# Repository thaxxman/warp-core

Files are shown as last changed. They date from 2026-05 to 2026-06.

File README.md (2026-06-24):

# 🔥 Warp Core eHMD

> **⚠️ WORK IN PROGRESS — Not Production Ready**
>
> This project is actively being developed and iterated. Hardware pin assignments, firmware behavior, BLE protocol fields, and the Android app UI are all **subject to change** without notice. Some components listed below may be obsolete or mislabeled. Build at your own risk, and expect to reflash the firmware as updates land. The final design is not yet stable.
>
> **Current challenges:**
> 1. **Power draw vs. PD limits** — When cold, the MCH element's inrush pulls hard enough to trip the overcurrent protection on the USB-C PD charger (100W / 20V 5A ceiling). Balancing startup current without sacrificing heat-up speed is still being worked out.
> 2. **MCH element selection** — Finding a ceramic MCH heating element that hits the right trade-off between wattage output and heat dispersion for this form factor. The current element works but isn't optimal.

An open-source Electronic Heat Management Device for hookah. The Warp Core replaces traditional charcoal with a PID-controlled MCH heating element, delivering precise, consistent temperature management through a sleek Android app and an on-device OLED display.





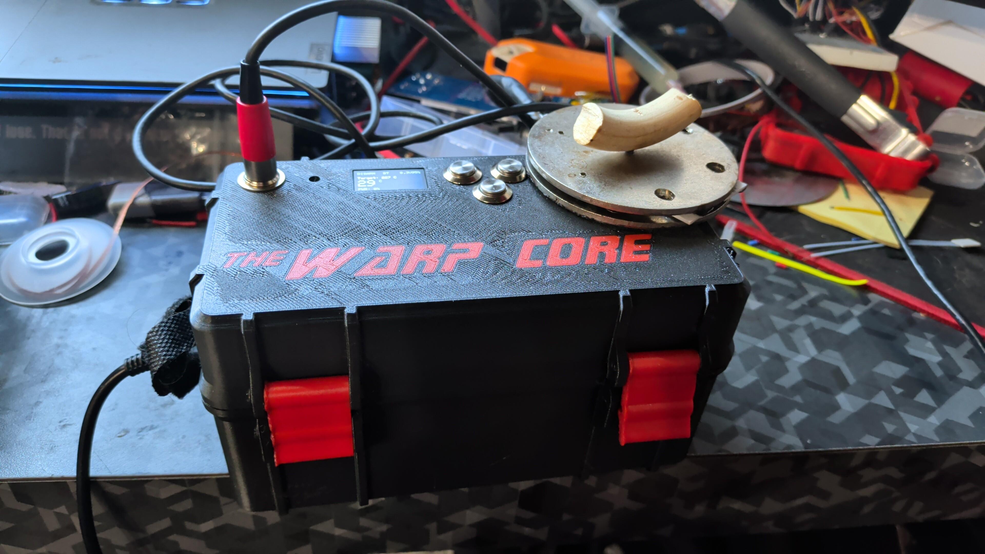
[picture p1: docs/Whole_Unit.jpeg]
Warp Core eHMD Assembled

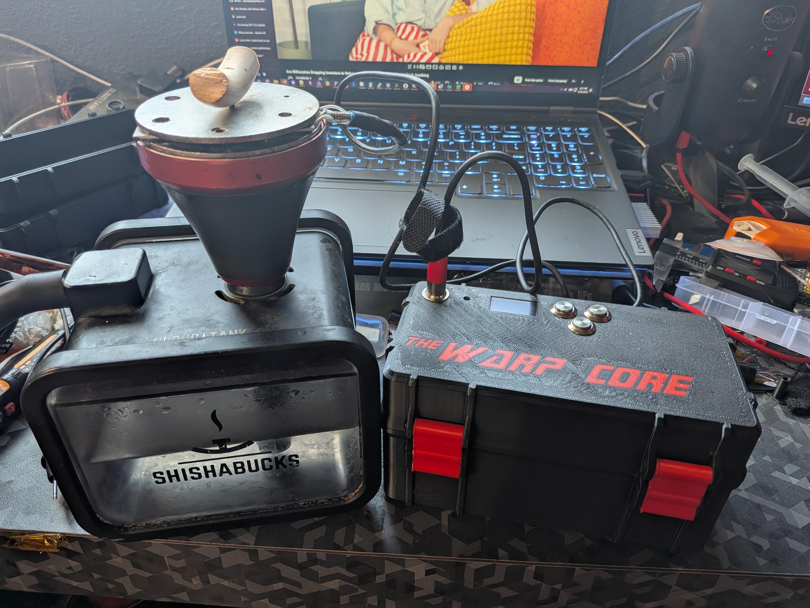
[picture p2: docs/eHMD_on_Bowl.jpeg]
Warp Core eHMD on Hookah

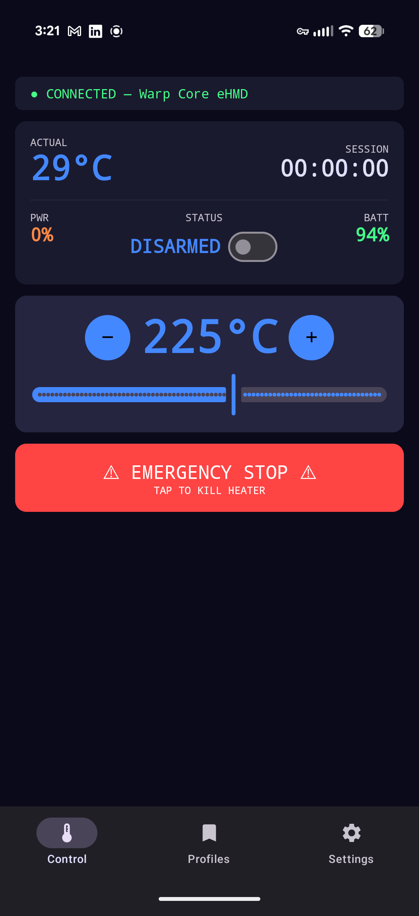
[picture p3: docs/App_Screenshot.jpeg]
Warp Core App Screenshot

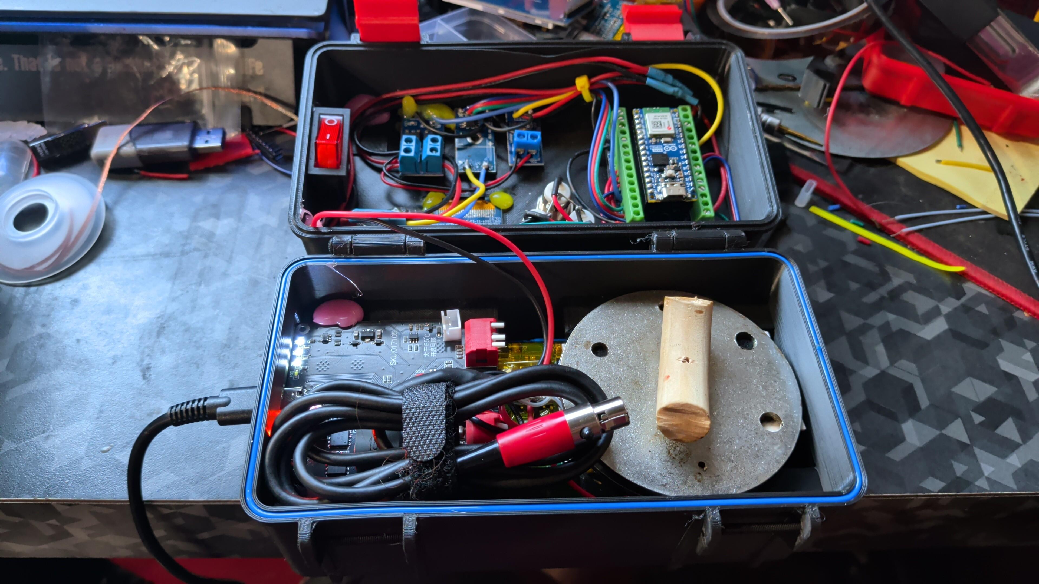
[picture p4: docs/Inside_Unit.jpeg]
Warp Core Inside


## What Is It?

The Warp Core eHMD is a DIY electronic heat management device that sits on top of a hookah bowl, replacing charcoal entirely. A K-type thermocouple reads the real-time temperature, a PID controller drives a ceramic MCH heating element via silent 20 kHz PWM, and an OLED screen on the base station shows you exactly what's happening — no guesswork.

The companion Android app connects over Bluetooth Low Energy and gives you a temperature slider, ±step buttons (configurable 1–10° per tap), preset profiles, live session graphs, and an emergency stop button. Set it, arm it, and let the Warp Core hold your temperature within a few degrees for the entire session.

**Key features:**

- **PID temperature control** — holds your set point within ±2°C at steady state
- **Silent operation** — 20 kHz MOSFET PWM, no audible coil whine
- **0–400°C range** — adjust from the app or on-device buttons
- **BLE Android app** — temperature control, profiles, session logging, CSV export
- **On-device OLED** — live temp, PWM output, safety ramp status, and session timer
- **Safety first** — thermal runaway detection, emergency stop, auto-disarm on fault
- **Configurable step size** — ±1° to ±10° per button tap, set in the app's Settings
- **Open source** — hardware + firmware + app, MIT license, build your own

---

## How It Works

The device has two physical assemblies:

**The eHMD Head** — a layered sandwich that sits on the hookah bowl:
1. Bottom steel plate — the foundation, drilled for the M3 clamp screw
2. Graphite thermal sheet — distributes heat evenly across the MCH element
3. MCH ceramic heating element — the business end, driven by the MOSFET
4. Carbon wool — insulates heat upward into the bowl, not downward
5. Top steel plate — clamps everything down, countersunk for the M3 screw

A K-type thermocouple tip sits in a cutout in the graphite layer, reading the actual interface temperature. The whole stack is clamped together with a steel M3 screw through the center, with a wooden handle on the protruding end.

**The Base Station** — the electronics box that houses:
- Arduino Nano ESP32 (brains + BLE radio)
- SSD1306 128×64 OLED display (I2C on D2/SDA, D3/SCL)
- 3 navigation buttons (left, right, press/select)
- MOSFET trigger board driving the MCH element (PWM on D4)
- MAX6675 thermocouple amplifier
- Piezo buzzer for alerts
- Powered by any **20V 5A USB-C PD** source — no internal battery, no battery monitoring

The head and base station connect via a 4-conductor cable with Mini XLR connectors — two wires for MCH power (18 AWG minimum) and two for the thermocouple signal.

---

## Bill of Materials

### Per-Unit Hardware (what goes into one device)

| Component | Unit Cost | Source |
|---|---|---|
| Steel Plate (2×) | $9 | [Amazon](https://www.amazon.com/dp/B0FWJNRSWB) |
| MCH Heating Element | $16 | [AliExpress](https://www.aliexpress.us/item/3256808961658582.html) |
| Arduino Nano ESP32 | $21 | [Amazon](https://www.amazon.com/dp/B0C947BHK5) |
| OLED Screen (1 of 5-pack) | $2.60 | [Amazon](https://www.amazon.com/dp/B0F5WPZJ92) |
| Voltage Detection Board (1 of 5) | $1.20 | [Amazon](https://www.amazon.com/dp/B01HTC4XKY) |
| MOSFET Trigger Board (1 of 6) | $0.83 | [Amazon](https://www.amazon.com/dp/B0FMJH3DML) |
| Push Buttons (3 of 5) | $3.60 | [Amazon](https://www.amazon.com/dp/B0FM8QKSM1) |
| Arduino Expansion Board (1 of 3) | $4.00 | [Amazon](https://www.amazon.com/dp/B0C9TMRL13) |
| Graphite Thermal Sheet | $0.29 | [Amazon](https://www.amazon.com/dp/B0C69BDLPX) |
| Carbon Wool | $0.10 | [Amazon](https://www.amazon.com/dp/B0CFL5PZWC) |
| K-Type Thermocouple (1 of 5) | $2.40 | [Amazon](https://www.amazon.com/dp/B0D17S7N5B) |
| **Per-unit subtotal** | **~$51** | |

**Per-unit total: ~$51 (battery-less)** — the design no longer uses an internal battery pack. Power via 20V USB-C PD.

### Consumables (buy once, use across many builds)

| Item | Cost | Per-Unit Burn |
|---|---|---|
| Kapton Tape | $10 | ~$0.25 |
| Screw Kit | $6 | ~$0.15 |
| Silicone Wire Kit | $12 | ~$0.50 |
| PLA Filament (1 kg, uses ~250g) | $19 | $4.75 |

**Max out-of-pocket: ~$66**

---

## Wiring Diagram

| Pin | Function | Direction |
|-----|---|---|
| D4 | MOSFET Signal | Output (digitalWrite bang-bang, ~50 Hz cycle) |
| D5 | Press/Select Button | Input (PULLUP) |
| D6 | Right Button | Input (PULLUP) |
| D7 | Left Button | Input (PULLUP) |
| D8 | Buzzer | Output (PWM ch0) |
| D10 | MAX6675 SCK | Output |
| D11 | MAX6675 CS | Output |
| D12 | MAX6675 SO | Input |
| D2 | OLED SDA (I2C) | I/O |
| D3 | OLED SCL (I2C) | Output |
| VIN | System power (20V USB-C PD) | Power in |
| 3V3 | Sensor power (3.3V) | Power out |

All buttons wire between their pin and GND — internal pull-ups are enabled, no external resistors needed.

See [Wiring Diagram](docs/Wiring%20Diagram.md) for full connection details.

---

## Assembly Instructions

Complete step-by-step build guide including LiPo safety briefing, battery pack assembly, Arduino IDE setup, thermocouple welding, and eHMD head construction:

**[Assembly Instructions →](docs/ASSEMBLY_INSTRUCTIONS.md)**

---

## Quick Start

### Flash the Arduino

1. Install [Arduino IDE 2.x](https://www.arduino.cc/en/software)
2. Add ESP32 board support — `File → Preferences → Additional Board Manager URLs`:
   ```
   https://espressif.github.io/arduino-esp32/package_esp32_index.json
   ```
3. Install the board package: `Tools → Board → Boards Manager → search "esp32" → Install`
4. Select **Arduino Nano ESP32** and the correct serial port
5. Install these libraries via `Sketch → Include Library → Manage Libraries`:

| Library | Author |
|---|---|
| Adafruit GFX Library | Adafruit |
| Adafruit SSD1306 | Adafruit |
| MAX6675 | Adafruit |
| PID_v1 | Brett Beauregard |
| ArduinoJson | Benoit Blanchon (v7) |

6. Open `arduino/WarpCore_eHMD.ino` and click **Upload**
7. Open Serial Monitor at 115200 baud to verify boot

### Install the Android App

1. Download `WarpCore-v1.0-debug.apk` from [Releases](../../releases)
2. Enable "Install from unknown sources" on your Android device
3. Install the APK
4. Grant Bluetooth and Location permissions on first launch
5. Power on the Warp Core, tap **Connect**

### Build from Source

```bash
cd android-app
./gradlew assembleDebug
# APK output: app/build/outputs/apk/debug/WarpCore-v1.0-debug.apk
```

---

## BLE Protocol

The ESP32 advertises as **"WarpCore-eHMD"** and exposes a single service:

- **Write characteristic** — app sends JSON: `{"cmd":"set_temp","val":200}`, `{"cmd":"arm","val":1}`, `{"cmd":"e_stop"}`, etc.
- **Notify characteristic** — ESP32 pushes status every 500ms: `{"status":"ok","temp_set":200,"temp_actual":198,"armed":1,"pwm":45,"session":120}`

Full protocol docs: [docs/BLE_PROTOCOL.md](docs/BLE_PROTOCOL.md)

---

## 3D Printed Enclosure

STL files in `docs/`:
- Box Bottom
- Box Lid
- Box Latch

---

## Project Structure

```
WarpCore-eHMD/
├── android-app/          # Kotlin + Jetpack Compose Android app
│   └── app/src/main/java/com/redshirt/warpcore/
│       ├── ble/          # BLE scan, connect, JSON protocol
│       ├── data/         # Room database (profiles, session logs)
│       ├── ui/           # Compose UI (screens, components, theme, navigation)
│       └── viewmodel/    # ConnectionViewModel, SettingsViewModel
├── arduino/             # ESP32 firmware
│   ├── WarpCore_eHMD.ino
│   └── pitches.h
├── docs/
│   ├── ASSEMBLY_INSTRUCTIONS.md
│   ├── BLE_PROTOCOL.md
│   ├── TODO.md
│   ├── Wiring Diagram.md
│   ├── Warp Core - Box Bottom.stl
│   ├── Warp Core - Box Lid.stl
│   └── Warp Core - Box Latch.stl
├── LICENSE
└── README.md
```

---

## Safety

This device controls a heating element that can reach **400°C (752°F)**.

- **Safety ramp**: When arming, PWM is capped at 40% until the thermocouple reads 50°C, then linearly ramps to full power at 200°C. This prevents runaway if the heater is powered before it's properly seated on the bowl
- **Thermal runaway protection**: If actual temp exceeds set temp by 50°C for 5 consecutive readings (~1.25s), the heater is killed, armed state cleared, and an alarm sounds
- **Never** leave the device unattended while armed
- The emergency stop button (long-press on device or in-app button) immediately kills heater power

You are responsible for safe assembly and operation. This project is provided as-is with no warranty.

---

## License

[MIT License](LICENSE) — use it, mod it, sell it. Just include the original license.

---

*Built by [George Thaxton](https://github.com/Thaxxman). Open source, open invitation.*

[☕ Buy me a Bowl](https://paypal.me/GThaxton)

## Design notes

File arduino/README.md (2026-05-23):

# Warp Core eHMD — Arduino Firmware

## Overview
Electronic Heat Management Device firmware for Arduino Nano ESP32.
Controls a heating element via PID, reads temperature from MAX6675 thermocouple,
displays on SSD1306 OLED, and communicates with the Android app over BLE.

## Hardware Pin Mapping (Arduino Nano ESP32)

| Pin | Function |
|-----|---|
| D9  | MOSFET PWM (heater control) |
| D10 | MAX6675 SCK |
| D11 | MAX6675 CS |
| D12 | MAX6675 SO (MISO) |
| D5  | Joystick Press (arm/disarm & set mode) |
| D6  | Joystick Right (temp up) |
| D7  | Joystick Left (temp down) |
| D8  | Buzzer (PWM audio) |
| A7  | Battery voltage divider |

## Required Libraries
Install via Arduino Library Manager (Sketch → Include Library → Manage Libraries):

1. **Adafruit GFX Library** — Display graphics
2. **Adafruit SSD1306** — OLED driver
3. **MAX6675** — Thermocouple library (or use the raw library included)
4. **PID_v1** — PID controller
5. **ArduinoJson** — v7, JSON parsing for BLE commands

ESP32 BLE libraries are built into the ESP32 Arduino Core — no separate install needed.

## Board Setup
- Board: "Arduino Nano ESP32" (or "ESP32 Dev Module" if using generic ESP32)
- The code uses `analogSetAttenuation`, `analogReadResolution`, and ESP32-specific `ledc` functions

## Building & Flashing
1. Open `WarpCore_eHMD.ino` in Arduino IDE
2. Select Board: Arduino Nano ESP32
3. Select Port: (your device's COM port)
4. Click Upload

## BLE Protocol
See `../docs/BLE_PROTOCOL.md` for the full specification.

## Local Controls (Buttons)
- **Long press (>3s)**: Arm / Disarm (3s hold)
- **Short press**: Enter / Exit set mode
- **Left/Right in set mode**: Adjust temperature (±1, hold for ±5)
- All local changes are reflected in the next BLE status update

## Safety Features
- Max temperature: 400°C (enforced in firmware and app)
- Thermal runaway: If actual temp exceeds set temp by 50°C for 5 consecutive readings (~1.25s), heater is killed, armed state cleared, alarm sounds
- Sensor fault: If thermocouple reads NaN, heater is killed and alarm sounds
- Emergency stop: App sends `{"cmd":"e_stop"}`, immediately kills heater

## EEPROM Layout
Stores: setTemp (double), Kp (double), Ki (double), Kd (double)
Values persist across power cycles. Defaults to 100°C, Kp=2, Ki=5, Kd=1.

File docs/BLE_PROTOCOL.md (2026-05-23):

# Warp Core eHMD — BLE Protocol Specification

## GATT Service Definition

| Item | UUID |
|---|---|
| Service | `4fafc201-1fb5-459e-8fcc-c5c9c331914b` |
| Write Characteristic (App → ESP32) | `beb5483e-36e1-4688-b7f5-ea07361b26a8` |
| Notify Characteristic (ESP32 → App) | `beb5483e-36e1-4688-b7f5-ea07361b26a9` |

## MTU

Request 512-byte MTU on connection. All messages fit well within this.

## Connection Parameters

- Request connection interval: 30-50ms (for responsive slider control)
- ESP32 advertises as: `Warp Core eHMD`

## Data Format

All messages are JSON. One command per BLE write. One status update per notify.

---

## App → ESP32 Commands (Write Characteristic)

### Set Target Temperature
```json
{"cmd":"set_temp","val":200}
```
- `val`: integer, 0–400 (Celsius)
- ESP32 enforces 0–400 range independently

### Arm / Disarm
```json
{"cmd":"arm","val":1}
```
```json
{"cmd":"arm","val":0}
```
- `val`: 1 = arm, 0 = disarm

### Emergency Stop
```json
{"cmd":"e_stop"}
```
- ESP32 immediately kills heater PWM, sets armed = false, sounds alarm tone
- App should send this repeatedly until acknowledged

### Request Full Status
```json
{"cmd":"get_status"}
```
- ESP32 responds with full state notify

### Set PID Parameters
```json
{"cmd":"set_pid","kp":2.0,"ki":5.0,"kd":1.0}
```
- Values stored in EEPROM alongside setTemp
- Only available via app (advanced settings)

---

## ESP32 → App Notifications (Notify Characteristic)

### Periodic Status Update (every 500ms when connected)
```json
{"status":"ok","temp_set":200,"temp_actual":198,"armed":1,"pwm":73,"battery":85,"session":1847}
```

| Field | Type | Unit | Notes |
|---|---|---|---|
| `status` | string | — | "ok", "error", "red_alert" |
| `temp_set` | int | °C | Current target temperature |
| `temp_actual` | float | °C | From thermocouple, -1 if sensor error |
| `armed` | int | — | 1 = armed, 0 = disarmed |
| `pwm` | int | % | PWM output as percentage (0–100) |
| `battery` | int | % | Battery level |
| `session` | int | seconds | Elapsed seconds since arm, 0 if disarmed |

### Red Alert (Thermal Runaway)
```json
{"status":"red_alert","temp_set":200,"temp_actual":267,"armed":0,"pwm":0,"battery":85,"session":1847}
```
- Heater is killed (`armed` = 0, `pwm` = 0)
- Buzzer sounds on device
- App should show prominent Red Alert UI

### Sensor Error
```json
{"status":"error","msg":"sensor_fault","temp_actual":-1}
```

### Disconnection Notification
On BLE disconnect, ESP32:
- Continues current operation (stays armed if armed)
- Sounds disconnect tone (ascending then descending tone)
- Shows BT disconnect icon on OLED
- Does NOT shut down heater

---

## Session Timer Logic

- Timer starts when `armed` transitions 0 → 1
- Timer resets to 0 when `armed` transitions 1 → 0
- Timer value included in every status update as `session` (integer seconds)
- Timer continues even if BLE disconnects and reconnects

---

## Thermal Runaway Detection

- Triggered when `temp_actual` exceeds `temp_set` by 50°C for 5 consecutive readings (readings at 250ms intervals = ~1.25 seconds sustained)
- Actions: kill heater, set armed = 0, sound alarm tone on buzzer, send red_alert status, show "RED ALERT" on OLED
- Latched: requires manual disarm/rearm or app e_stop + rearm to clear

---

## F/C Conversion

All BLE communication uses Celsius. The app is responsible for:
- Displaying in user's preferred unit (set in app settings)
- Converting slider/input values from F→C before sending `set_temp`
- Converting received `temp_actual` and `temp_set` from C→F for display (when F mode active)

Conversion: F = C × 9/5 + 32, C = (F − 32) × 5/9

---

## Profiles

Profiles are stored only on the app side (not on ESP32). A profile contains:
- Name (string)
- Target Temp (integer, stored in preferred unit, sent as °C)

The app sends a normal `set_temp` command when applying a profile. No special protocol needed.

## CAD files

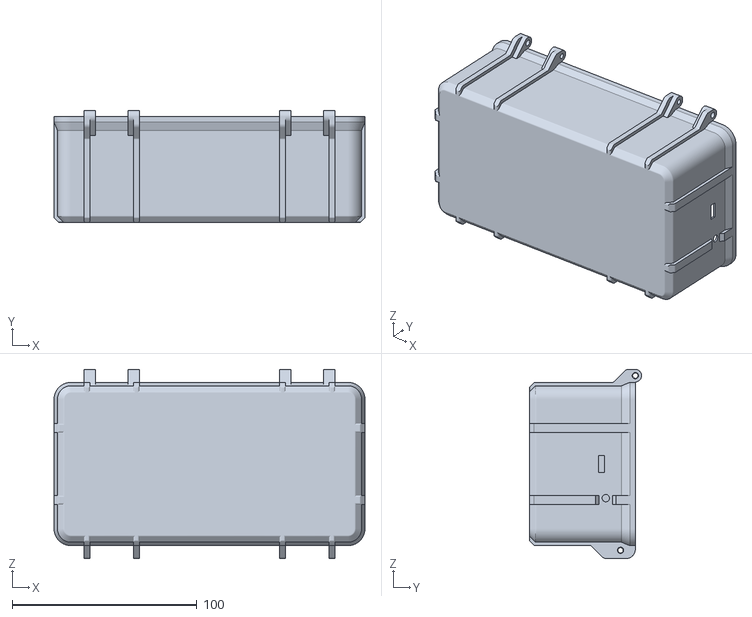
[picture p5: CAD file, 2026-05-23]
docs/Warp Core - Box Bottom.stl
168.5 x 60.8 x 102.5

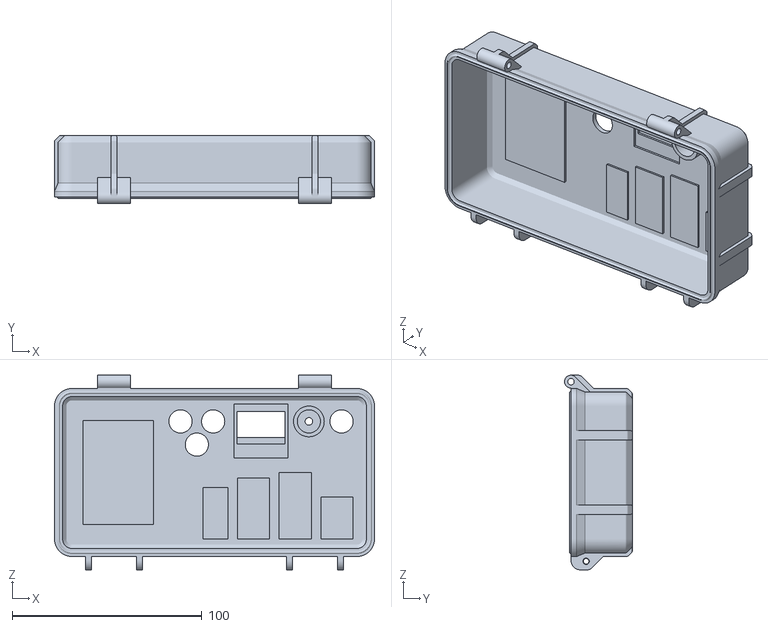
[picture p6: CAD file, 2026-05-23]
docs/Warp Core - Box Lid.stl
168.5 x 35.8 x 102.5

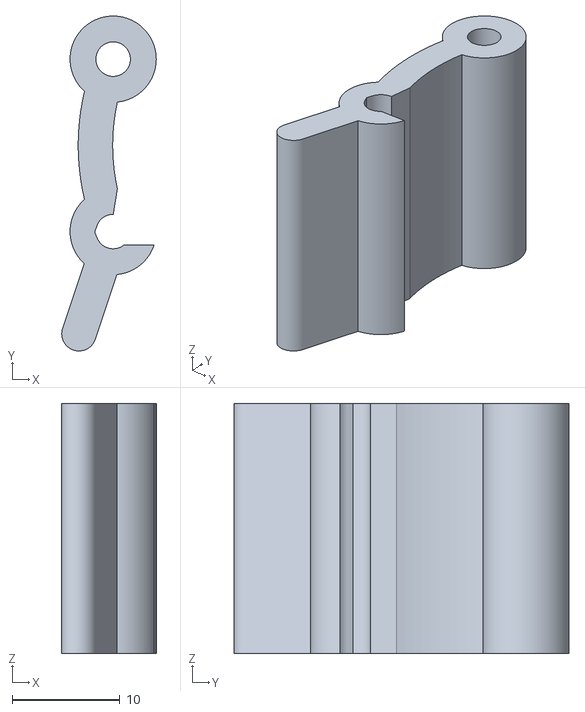
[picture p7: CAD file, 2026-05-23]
docs/Warp Core - Box Latch.stl
8.77 x 31.1 x 23.2

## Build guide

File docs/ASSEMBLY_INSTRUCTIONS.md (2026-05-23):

# Warp Core eHMD — Arduino Nano ESP32 Assembly Instructions

## 1. 3D Print the Enclosure

Print the included STL files. Recommended settings:

- **Material:** PLA (or PETG for higher heat resistance near the heater)
- **Infill:** 20–30%
- **Walls:** 3 perimeters minimum
- **Supports:** Per STL — review each for overhangs before printing

Assemble printed parts with M3 screws.

---

## 2. Wire the Arduino Components

Place and wire all components following the wiring guide below. Secure each component with hot glue. Keep wire runs as short as practical. Use zip ties where needed to manage routing.

| Component | Wire | ESP32 Pin | Notes |
|---|---|---|---|
| **MAX6675 Thermocouple** | | | |
| | SCK | D10 | SPI clock |
| | CS | D11 | Chip select |
| | SO | D12 | SPI data out |
| | VCC | 3V3 | |
| | GND | GND | |
| **MOSFET Trigger Board** | | | |
| | Signal | D9 | PWM ch1, 20 kHz (ultrasonic) |
| | VCC | VIN (5V from battery) | |
| | GND | GND | |
| **Buzzer** | | | |
| | + | D8 | PWM ch0 |
| | − | GND | |
| **Left Button** | | | |
| | Common | GND | |
| | NO | D7 | INPUT_PULLUP — no resistor needed |
| **Right Button** | | | |
| | Common | GND | |
| | NO | D6 | INPUT_PULLUP — no resistor needed |
| **Press/Select Button** | | | |
| | Common | GND | |
| | NO | D5 | INPUT_PULLUP — no resistor needed |
| **OLED Display (SSD1306)** | | | I2C address 0x3C |
| | SDA | A4 | I2C data |
| | SCL | A5 | I2C clock |
| | VCC | 3V3 | |
| | GND | GND | |
| **Voltage Detection Board** | | | |
| | Signal out | A7 | Analog read |
| | VCC | Battery + | Monitors pack voltage |
| | GND | GND | |

**Unused GPIOs:** D2, D3, D4 are available for future expansion.

**Power routing:**
- **VIN** receives 5V from the charging module output (powers the ESP32 and MOSFET board)
- **3V3** powers the thermocouple IC, OLED, and logic-level references
- **GND** is common to all components — star ground preferred

---

## 3. Assemble the 2S2P Battery Pack

### ⚠️ LIPO SAFETY BRIEFING — READ THIS ENTIRE SECTION BEFORE STARTING

Lithium Polymer (LiPo) batteries store enormous energy in a small package. Mishandling them can cause **fire, explosion, chemical burns, and property damage.** Treat them with the same caution you'd give to a loaded firearm.

**The risks are real:**

- A punctured, overcharged, or shorted LiPo cell can undergo **thermal runaway** — the cell vents hot gas, catches fire, and cannot be extinguished with water or a standard fire extinguisher. It burns until the fuel is spent.
- A **2S pack** sits at 8.4V when fully charged. Shorting the terminals will dump 30+ amps instantly — enough to melt wire, weld metal, and start a fire.
- **Never** charge a swollen, dented, or damaged cell. Dispose of it instead.
- **Never** charge unattended. Stay in the same room.
- **Never** puncture, crush, or disassemble a cell.
- **Never** short the terminals together, even momentarily.
- **Always** charge on a non-flammable surface (concrete, ceramic tile, steel). Not on a desk, not on carpet, not on wood.
- **Keep a LiPo fire bag or sand bucket nearby** when charging. A class D fire extinguisher is ideal; a standard ABC extinguisher will not stop a LiPo fire.
- If a cell **swells, gets hot to the touch, or smells sweet/burnt**, move it outdoors away from combustibles immediately and do not use it again.

**You are responsible for your own safety.** If you are not comfortable working with LiPo cells, ask someone with experience to help.

### Assembly Instructions

You need: **4× 146074 LiPo cells** (2 pairs in parallel, those 2 pairs in series), **1× 2S BMS board**, **silicone wire** (18AWG for power, 22–26AWG for balance), **heat shrink tubing** (for each cell and for the pack), **soldering iron**, **multimeter**, **Kapton tape**.

**Step 1 — Inspect and charge cells individually**

- Check each cell for swelling, dents, or damage. Discard any suspect cell.
- Charge each cell individually to **3.8V (storage charge)** using a balance charger. All four cells must be within **0.05V** of each other before proceeding. Mismatched cells will cause the BMS to cut off prematurely or, worse, overcharge one pair.

**Step 2 — Heat shrink each cell**

- Cut a length of battery heat shrink tubing for each cell. Slide it over the cell and shrink with a heat gun on **low setting** — keep the gun moving. Do not over-shrink; you need the tubing to lie flat. This insulates each cell from its neighbors.

**Step 3 — Create the parallel pairs**

- Place two cells **side by side, same orientation** (both + facing the same direction).
- Tape the pair together with Kapton tape. Wrap tightly but do not crush.
- Solder a short bus wire across the **positive terminals** of both cells. Keep the solder joint small and flat.
- Solder a short bus wire across the **negative terminals** of both cells.
- You now have a "1S2P" cell group rated at ~3.7V nominal, double the capacity. Repeat for the second pair.

**Step 4 — Wire the BMS**

Before soldering, study your BMS pinout. Most 2S BMS boards have these pads:

| Pad | Connects To |
|-----|---|
| B− | Negative of the **lower** cell pair (Pack −) |
| B1 | Junction between the two cell pairs (balance tap) |
| B+ | Positive of the **upper** cell pair (Pack +) |
| P− | Pack output negative (to charging module) |
| P+ | Pack output positive (to charging module) |

- Solder **B−** to the negative of the lower pair.
- Solder **B1** to the junction between the pairs (the common midpoint).
- Solder **B+** to the positive of the upper pair.
- Use **short, thick (18AWG silicone) wires** for P− and P+. These carry full load current.
- Wrap the BMS in Kapton tape to prevent shorts against the cell cans.

**Step 5 — Shrink the full pack**

- Wrap the entire assembly (both pairs + BMS) in battery heat shrink. This holds it together and adds puncture resistance.
- Leave the P+ and P− leads extending out the top, along with the balance leads if your BMS has a separate balance connector.

**Step 6 — Verify with a multimeter**

- Measure the pack voltage at P+ / P−. It should read between **7.4V** (nominal) and **8.4V** (fully charged).
- Measure the midpoint (B1 relative to B−). It should read **~3.7V**.
- If either reading is off by more than 0.1V, **stop and troubleshoot.** A wiring mistake here will destroy the BMS or the cells on the first charge cycle.

---

## 4. Install the Arduino Software

### Install the Arduino IDE

1. Download the Arduino IDE from [https://www.arduino.cc/en/software](https://www.arduino.cc/en/software) (version 2.x recommended).
2. Install it for your operating system (Windows, macOS, or Linux).

### Add ESP32 Board Support

The Arduino Nano ESP32 is not in the default board package. You need to add Espressif's board definitions:

1. Open Arduino IDE → **File → Preferences**.
2. In **Additional Board Manager URLs**, add:
   ```
   https://espressif.github.io/arduino-esp32/package_esp32_index.json
   ```
   (If you already have other URLs, click the button next to the field and add this one on a new line.)
3. Click **OK**.
4. Go to **Tools → Board → Boards Manager**.
5. Search for **esp32**. Install **esp32 by Espressif Systems** (version 3.x or later).

### Select the Board and Port

1. Connect the Arduino Nano ESP32 to your computer via USB-C.
2. Go to **Tools → Board** → select **Arduino Nano ESP32** (under "ESP32 Arduino" group).
3. Go to **Tools → Port** → select the COM port (Windows) or `/dev/cu.usbmodem*` (macOS) that appeared when you plugged in the board.
4. If the board doesn't appear, double-tap the reset button on the Nano to put it in bootloader mode, then try again.

### Install Required Libraries

Go to **Sketch → Include Library → Manage Libraries** and install each of these:

| Library | Author | Version |
|---|---|---|
| Adafruit GFX Library | Adafruit | Latest |
| Adafruit SSD1306 | Adafruit | Latest |
| MAX6675 | Adafruit | Latest |
| PID_v1 | Brett Beauregard | Latest |
| ArduinoJson | Benoit Blanchon | v7.x |

**Important:** Do **NOT** install the "ArduinoBLE" library — the ESP32 Nano uses its built-in NimBLE stack (BLEDevice.h / BLEServer.h), not ArduinoBLE. ArduinoBLE requires a NINA-W102 coprocessor that the ESP32 Nano does not have.

### Upload the Firmware

1. Open the file `arduino/WarpCore_eHMD.ino` from this project.
2. Make sure the board is set to **Arduino Nano ESP32** and the correct port is selected.
3. Click **Upload** (→ arrow button) or press **Ctrl+U**.
4. The IDE will compile and flash the firmware. The Nano's LED will pulse during upload and then the OLED should initialize on reboot.
5. Open **Tools → Serial Monitor** at **115200 baud** to verify boot messages and BLE advertising.

---

## 5. Install the Warp Core Android App

1. Copy the provided `app-debug.apk` to your Android phone.
2. On the phone, open the APK file. You may need to enable **"Install from unknown sources"** in Settings → Security.
3. Install and open the app.
4. Grant Bluetooth and Location permissions when prompted (required for BLE scanning on Android).

---

## 6. Assemble the eHMD

### 6a. Drill the Bottom Plate

- Drill **8× 6mm holes** equidistant around the perimeter. Each hole should have **at least 6mm** of material between the hole edge and the plate edge. These are airflow / ventilation holes for the heater.
- Drill **1× 3mm hole** in the center of the bottom plate. **Countersink** this hole from the top side so the screw head sits flush or slightly below the surface.
- Lightly deburr all holes with a file or deburring tool.

### 6b. Drill and Tap the Top Plate

- Drill a **2.5mm hole** in the center of the top plate (tap drill size for M3).
- **Tap** the hole with an **M3×0.5 thread tap**. Go slow, use cutting oil if available, back the tap out frequently to clear chips. The steel plate is thin — run the tap through 2–3 times to clean the threads.

### 6c. Prepare the Thermocouple Probe

The K-type thermocouple wire is two dissimilar metals (chromel and alumel) welded together at the tip. If you need to shorten or repair the probe:

1. **Strip** the end of the thermocouple wire to expose about 5mm of each conductor (the positive wire is typically non-magnetic chromel, the negative is magnetic alumel).
2. **Twist** the two bare conductors tightly together at the tip.
3. **Weld** the junction using a capacitor-discharge welder, a spot welder, or the "battery method":
   - Take a **fresh AA or 9V battery**.
   - Touch the twisted thermocouple junction briefly to the battery terminal while simultaneously brushing it against the other terminal. The rapid current pulse will resistance-weld the junction.
   - Alternatively, touch the twisted tip to a **lead** strip while applying power from a bench supply (3–5V, current-limited to ~10A) for a split second. The lead melts and fuses the junction.
4. **Test** the joint with your multimeter set to millivolts. Warm the tip with your fingers — you should see a small voltage change (roughly 0.04mV per °C).
5. Insulate the wires above the junction with a small piece of **Kapton tape** or fiberglass sleeving. The junction itself must remain exposed (metal-to-metal contact with the graphite sheet).

Cut the thermocouple to roughly **5 inches** (127mm) overall length before welding the tip. This gives enough wire to route from the eHMD down to the Arduino, with some slack for strain relief.

### 6d. Layer Assembly

Sandwich the eHMD layers in this order, bottom to top:

| Layer | Component | Notes |
|---|---|---|
| **L1** | Bottom plate | Countersunk center hole facing up |
| **L2** | Graphite sheet | Cut to match the MCH element footprint. Cut a small notch or pocket for the thermocouple tip — the tip must be in direct contact with the graphite. |
| **L3** | MCH heating element | Flat side against the graphite |
| **L4** | Carbon wool | Layer thick enough to fully cover the MCH. This is your thermal insulation and heat distributor. |
| **L5** | Top plate | M3 threaded center hole |

### 6e. Clamp Together

1. Run a **steel M3×20mm screw** up through the bottom plate (from below, countersunk head sits flush), through L2, L3, L4, and thread it into the tapped center hole of the top plate (L5).
2. Tighten firmly — the clamping force should be tight enough to compress the carbon wool slightly and ensure good thermal contact between all layers. Don't overtighten to the point of crushing the MCH element.
3. The 20mm screw leaves ~5–8mm of excess above the top plate. Thread a **wooden handle** onto this protruding stud for easy lifting of the hot eHMD.

### 6f. Wire the MCH and Thermocouple to the Cable

1. Solder the **MCH heating element** leads to a 4-conductor cable:
   - **MCH + (red)** → 18AWG wire (minimum) → XLR pin 1 (or per your XLR pinout)
   - **MCH − (black)** → 18AWG wire (minimum) → XLR pin 2
   - 18AWG is required because the MCH can draw 5–10A at operating voltage.
2. Solder the **K-type thermocouple** leads to the remaining 2 conductors in the cable:
   - **Chromel (+)** → smaller gauge wire → XLR pin 3
   - **Alumel (−)** → smaller gauge wire → XLR pin 4
3. Cover each solder joint with **heat shrink tubing**. Slide the tubing over the joint and shrink with a heat gun.
4. Wrap the entire cable junction with Kapton tape for strain relief and insulation.

### 6g. Install the Mini XLR Connector

At the **base station end** of the cable:

1. Install the **4-pin Mini XLR connector** on the cable end.
2. Pin assignment must match the female socket on the base station:
   - **Pins 1 & 2:** Load output from the MOSFET trigger board (MCH + and −)
   - **Pins 3 & 4:** Thermocouple input to the MAX6675 chip on the Arduino
3. Verify continuity with a multimeter before powering on. A swapped thermocouple polarity will cause the displayed temperature to **decrease** as the heater warms up — an easy mistake to catch.

---

## 7. Charge Before First Use

1. Connect the USB-C charging module to a **65W+ USB-C PD power supply** (laptop charger or similar).
2. A full charge from storage voltage takes approximately **1.5–2 hours**.
3. The BMS will balance the cells and cut off at 8.4V (4.2V per cell).
4. Do not leave charging unattended overnight for the first cycle. Monitor for any swelling, heat, or unusual odor.

---

## 8. Maiden Voyage

1. **Power on** the Arduino Nano ESP32 via USB-C or from the battery through the charging module.
2. The OLED will display the boot screen. The buzzer will play the startup melody.
3. BLE will advertise as **"WarpCore-eHMD"** for **2 minutes**. Open the Android app and tap **Connect**.
4. Once connected, the app transitions to the **Control** screen. You should see the current temperature, set temperature, and controls.
5. **Set your target temperature** using the slider or ± buttons. Default step size is ±1° (adjustable in Settings → Step Size).
6. Press **ARM** to begin heating. The MOSFET will energize and the PID controller will ramp up to target.
7. Monitor the temperature readout. The app updates every 500ms. The OLED also displays live status.
8. When done, press **DISARM** to shut off the heater. The MOSFET drops to 0% PWM.
9. **Emergency Stop** is always available on the Control screen — it immediately kills the heater and sounds a triple-tone alert.

**Congratulate yourself, Captain. The Warp Core is online.** 🖖

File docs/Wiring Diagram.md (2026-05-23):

    Warp Core eHMD — Arduino Nano ESP32 Wiring Diagram

    ┌──────────────────────────────────────────┐
    │          ARDUINO NANO ESP32 (top view)   │
    │                                          │
    │  D13 ─ ─ ─ ─ ─ ─ ─ ─ ─ ─ ─ ─ ─ ─  D12    │
    │  3V3 ─ ─ ─ ─ ─ ─ ─ ─ ─ ─ ─ ─ ─ ─  D11    │
    │  REF ─ ─ ─ ─ ─ ─ ─ ─ ─ ─ ─ ─ ─ ─  D10    │
    │  A0  ─ ─ ─ ─ ─ ─ ─ ─ ─ ─ ─ ─ ─ ─  D9     │
    │  A1  ─ ─ ─ ─ ─ ─ ─ ─ ─ ─ ─ ─ ─ ─  D8     │
    │  A2  ─ ─ ─ ─ ─ ─ ─ ─ ─ ─ ─ ─ ─ ─  D7     │
    │  A3  ─ ─ ─ ─ ─ ─ ─ ─ ─ ─ ─ ─ ─ ─  D6     │
    │  A4  ─ ─ ─ ─ ─ ─ ─ ─ ─ ─ ─ ─ ─ ─  D5     │
    │  A5  ─ ─ ─ ─ ─ ─ ─ ─ ─ ─ ─ ─ ─ ─  D4     │
    │  A6  ─ ─ ─ ─ ─ ─ ─ ─ ─ ─ ─ ─ ─ ─  D3     │
    │  A7  ─ ─ ─ ─ ─ ─ ─ ─ ─ ─ ─ ─ ─ ─  D2     │
    │  5V  ─ ─ ─ ─ ─ ─ ─ ─ ─ ─ ─ ─ ─ ─  GND    │
    │  RST ─ ─ ─ ─ ─ ─ ─ ─ ─ ─ ─ ─ ─ ─  VIN    │
    │  GND ─ ─ ─ ─ ─ ─ ─ ─ ─ ─ ─ ─ ─ ─  3V3_EN │
    └──────────────────────────────────────────┘

    Signal Connections

    | Component               | Wire       | ESP32 Pin      | Notes                    |
    |-------------------------|------------|----------------|--------------------------|
    | MAX6675 Thermocouple    |            |                |                          |
    |                         | SCK        | D10            | SPI clock                |
    |                         | CS         | D11            | Chip select              |
    |                         | SO         | D12            | SPI data out             |
    |                         | VCC        | 3V3            |                          |
    |                         | GND        | GND            |                          |
    |                         | + Probe    | + to eHMD      | This runs to the Mini XLR|
    |                         | - Probe    | - to eHMD      | This runs to the Mini XLR|
    | MOSFET Trigger Board    |            |                |                          |
    |                         | Signal     | D9             | PWM ch1, 20 kHz          |
    |                         | VCC        | 5V or VIN      | From battery via step-up |
    |                         | GND        | GND            |                          |
    | MCH Heater Element      |            |                |                          |
    |                         | Load+      | MOSFET output+ | Through MOSFET board     |
    |                         | Load−      | MOSFET output− | Through MOSFET board     |
    | Buzzer                  |            |                |                          |
    |                         | +          | D8             | PWM ch0                  |
    |                         | −          | GND            |                          |
    | Left Button             |            |                |                          |
    |                         | Common     | GND            |                          |
    |                         | NO         | D7             | INPUT_PULLUP in code     |
    | Right Button            |            |                |                          |
    |                         | Common     | GND            |                          |
    |                         | NO         | D6             | INPUT_PULLUP in code     |
    | Press/Select Button     |            |                |                          |
    |                         | Common     | GND            |                          |
    |                         | NO         | D5             | INPUT_PULLUP in code     |
    | OLED Display (SSD1306)  |            |                | I2C address 0x3C         |
    |                         | SDA        | A4             | I2C data                 |
    |                         | SCL        | A5             | I2C clock                |
    |                         | VCC        | 3V3            |                          |
    |                         | GND        | GND            |                          |
    | Voltage Detection Board |            |                |                          |
    |                         | Signal out | A7             | Analog read              |
    |                         | VCC        | Battery+       | Monitors pack voltage    |
    |                         | GND        | GND            |                          |

    Power Section (battery build only)

    | Component            | Wire  | Connects To                  | Notes                    |
    |----------------------|-------|------------------------------|--------------------------|
    | 2S BMS               |       |                              |                          |
    |                      | B+    | Battery pack +               | 4× 146074 cells in 2S2P  |
    |                      | B−    | Battery pack −               |                          |
    |                      | P+    | 140W Charging Module VIN+    |                          |
    |                      | P−    | 140W Charging Module VIN−    |                          |
    | 140W Charging Module |       |                              |                          |
    |                      | USB-C | —                            | Charge input             |
    |                      | OUT+  | ESP32 VIN + MOSFET VCC       | Powers everything        |
    |                      | OUT−  | Power Switch -               |                          |
    | Power Switch         |       |                              |                          |
    |                      | -     | 140W Out -                   | Charge input             |
    |                      | -     | ESP32 VIN + MOSFET VCC       | Powers everything        |
    | Min XLR Connector    |       |                      		  | eHMD Head                |
    |                      | Pin 1 | + on the LOAD side of MOSFET |                          |
    |                      | Pin 2 | - on the LOAD side of MOSFET |                          |
    |                      | Pin 3 | + Thermal Probe on Max6687   |                          |
    |                      | Pin 2 | - Thermal Probe on Max6687   |                          |
    | Battery Heatshrink   | —     | Wraps each cell              | Insulation between cells |

    Voltage Divider (for battery monitoring — built from resistors or uses the voltage detection board)

    Battery+ ──┬── 30kΩ (rOhm1) ──┬── A7
                │                   │
                │               7.5kΩ (rOhm2)
                │                   │
                └───────────────── GND

    Calibrated with voltageCalibration = 1.1038. If using the voltage detection board from the BOM, it likely has this divider built in — just wire its signal out to A7.

    Summary of all ESP32 pin assignments:

    | Pin | Function            | Direction                |
    |-----|---------------------|--------------------------|
    | D2  | Available           | —                        |
    | D3  | Available           | —                        |
    | D4  | Available           | —                        |
    | D5  | Press/Select Button | Input (PULLUP)           |
    | D6  | Right Button        | Input (PULLUP)           |
    | D7  | Left Button         | Input (PULLUP)           |
    | D8  | Buzzer              | Output (PWM ch0)         |
    | D9  | MOSFET Signal       | Output (PWM ch1, 20 kHz) |
    | D10 | MAX6675 SCK         | Output                   |
    | D11 | MAX6675 CS          | Output                   |
    | D12 | MAX6675 SO          | Input                    |
    | A4  | OLED SDA (I2C)      | I/O                      |
    | A5  | OLED SCL (I2C)      | Output                   |
    | A7  | Voltage Sense       | Input (Analog)           |
    | VIN | System power (5V)   | Power in                 |
    | 3V3 | Sensor power (3.3V) | Power out                |
    | GND | Common ground       | Ground                   |

    Buttons are wired between the pin and GND — the code uses INPUT_PULLUP so no external resistors needed. When pressed, the pin goes LOW.

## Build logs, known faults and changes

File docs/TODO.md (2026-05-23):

# Warp Core eHMD — TODO List

## BLE Pairing (Goal — Not Yet Implemented)
- [ ] **Implement Numeric Comparison pairing** — display code on OLED, user taps Confirm on phone
  - Requires debugging v3.x NimBLE callback routing (onPassKeyNotify, onConfirmPIN)
  - The old Bluedroid callbacks don't fire in v3.x NimBLE core
  - May need direct ESP-IDF `esp_ble_gap_*` calls or switching back to Bluedroid mode

## BLE Connection (Current Status)
- [x] **Switched to ArduinoBLE.h** — Bluedroid API was broken on v3.x NimBLE core
- [x] **Just Works pairing works** — no PIN, no confirmation, just connects
- [ ] **Verify connection works end-to-end** — test actual data flow between app and ESP32
- [ ] **Test BLE timeout** — verify 2-min boot window and 30-sec reconnect window work

## Android App
- [x] **BLE Manager with permission checks** — SecurityException fix, scan-first connect flow
- [ ] **Verify JSON protocol flows** — send commands and receive status updates
- [ ] **Foldable layout** — Pixel 10 Fold support
- [ ] **Red Alert UI overlay** — visual warning when thermal runaway detected
- [ ] **Session logging** — save temp/PWM history to local DB

## Hardware / Firmware
- [ ] **OTA firmware updates** (v2 goal)
- [ ] **BLE wake button** — physical button to re-enable BLE without full reboot
- [x] **PWM standardized to ledc** — buzzer and MOSFET both use ledc API
- [x] **Thermal runaway detection** — Red Alert at 50°C over setTemp for 5 readings

## ArduinoBLE Migration Notes
- `BLEDevice::init()` → `BLE.begin()`
- `BLEServer::createService()` → `BLEService` constructor + `BLE.addService()`
- `BLECharacteristic::PROPERTY_WRITE_NR` → `BLEWriteWithoutResponse`
- `BLECharacteristic::PROPERTY_NOTIFY` → `BLENotify`
- `pCharacteristic->setValue()` + `notify()` → `writeValue()`
- `BLEServerCallbacks::onConnect/onDisconnect` → `BLE.poll()` + `BLE.central()` polling
- `BLECharacteristicCallbacks::onWrite` → `BLECharacteristic::setEventHandler(BLEWritten, handler)`
- No `BLE2902` descriptor needed — ArduinoBLE handles CCCD internally
- No `BLEDevice::setSecurityCallbacks()` — ArduinoBLE is no-config Just Works

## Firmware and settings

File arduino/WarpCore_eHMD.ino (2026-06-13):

/*
 * Warp Core eHMD — Electronic Heat Management Device
 * Arduino Nano ESP32 Firmware with BLE Support
 * 
 * Controls a heating element via PID-controlled PWM for hookah use.
 * Communicates with the Warp Core eHMD Android app over BLE.
 * 
 * Hardware:
 *   - MAX6675 thermocouple on pins D10 (SCK), D11 (CS), D12 (SO)
 *   - MOSFET on D4 — bang-bang (digitalWrite) control, was D9 moved due to GPIO 9 conflict
 *   - SSD1306 128x64 OLED on I2C (D2=SDA, D3=SCL)
 *   - Buttons: D5 (press/select), D6 (right), D7 (left)
 *   - Buzzer on D8 (PWM channel 0)
 * 
 * BLE Protocol: See docs/BLE_PROTOCOL.md
 * 
 * Libraries required:
 *   - ESP32 Arduino Core v3.x (built-in BLE — uses NimBLE)
 *   - Adafruit GFX Library
 *   - Adafruit SSD1306
 *   - MAX6675
 *   - PID_v1
 *   - ArduinoJson v7 (by Benoit Blanchon)
 *
 * IMPORTANT: Do NOT use ArduinoBLE library — it requires SpiNINA 
 *   (NINA-W102 coprocessor) which the ESP32 Nano does not have.
 *   Use the built-in BLEDevice.h / BLEServer.h / BLEUtils.h / BLE2902.h.
 */

#include <Wire.h>

// Custom I2C pins for OLED — reassigned from default A4/A5 to D2/SDA, D3/SCL
TwoWire myWire = TwoWire(0);

#include <Adafruit_GFX.h>
#include <Adafruit_SSD1306.h>
#include "max6675.h"
#include <PID_v1.h>
#include <EEPROM.h>
#include "pitches.h"

// BLE — ESP32 built-in NimBLE (NOT ArduinoBLE — requires SpiNINA coprocessor)
#include <BLEDevice.h>
#include <BLEServer.h>
#include <BLEUtils.h>
#include <BLE2902.h>
#include <ArduinoJson.h>
#include <math.h>

// ============================================================================
// BLE UUIDs
// ============================================================================
#define SERVICE_UUID        "4fafc201-1fb5-459e-8fcc-c5c9c331914b"
#define CHAR_WRITE_UUID    "beb5483e-36e1-4688-b7f5-ea07361b26a8"
#define CHAR_NOTIFY_UUID   "beb5483e-36e1-4688-b7f5-ea07361b26a9"

// ============================================================================
// EEPROM Layout
// ============================================================================
struct EEData {
  double setTemp;
  double Kp;
  double Ki;
  double Kd;
};

const int EEPROM_ADDR = 0;
const size_t EEPROM_SIZE = sizeof(EEData) + 64;

const double DEFAULT_SET_TEMP = 100.0;
const double DEFAULT_KP = 2.0;
const double DEFAULT_KI = 5.0;
const double DEFAULT_KD = 1.0;

// ============================================================================
// OLED Display
// ============================================================================
#define SCREEN_WIDTH 128
#define SCREEN_HEIGHT 64
#define OLED_RESET    -1
#define SCREEN_ADDRESS 0x3C
Adafruit_SSD1306 display(SCREEN_WIDTH, SCREEN_HEIGHT, &myWire, OLED_RESET);

// ============================================================================
// Hardware Pin Definitions (Arduino Nano ESP32)
// ============================================================================
const int PIN_MOSFET    = 4;
const int PIN_SO        = 12;
const int PIN_CS        = 11;
const int PIN_SCK       = 10;
const int BTN_LEFT      = 7;
const int BTN_RIGHT     = 6;
const int BTN_PRESS     = 5;
const int PIN_BUZZER    = 8;

MAX6675 thermocouple(PIN_SCK, PIN_CS, PIN_SO);

// ============================================================================
// PWM Channel Assignments (ESP32 ledc)
// ============================================================================
const int BUZZER_PWM_CHANNEL  = 0;
// MOSFET: driven by digitalWrite (bang-bang) — LEDC produced insufficient
// voltage on this board. Time-proportioned cycle gives smooth thermal control
// with zero audible noise. See MOSFET_CYCLE_MS below.
const int MOSFET_PWM_CHANNEL  = -1;  // unused — kept as guard constant

// ============================================================================
// Safety Limits
// ============================================================================
const double MAX_TEMP = 400.0;
const double THERMAL_RUNAWAY_DELTA = 50.0;
const int THERMAL_RUNAWAY_COUNT = 5;

// ============================================================================
// State Variables
// ============================================================================
bool systemArmed = false;
bool setMode = false;
double setTemp = DEFAULT_SET_TEMP;
double pendingTemp = DEFAULT_SET_TEMP;
double actualTemp = 0.0;
double pidOutput = 0.0;
double Kp = DEFAULT_KP;
double Ki = DEFAULT_KI;
double Kd = DEFAULT_KD;

PID myPID(&actualTemp, &pidOutput, &setTemp, Kp, Ki, Kd, DIRECT);

unsigned long lastTempTime = 0;
unsigned long lastDisplayUpdate = 0;
unsigned long lastAlarmTime = 0;

unsigned long buttonPressedTime = 0;
const int LONG_PRESS_DURATION = 3000;

unsigned long sessionStartTime = 0;
unsigned long sessionElapsed = 0;

int thermalRunawayCount = 0;
bool redAlertActive = false;

bool targetReachedNotified = false;

// ============================================================================
// Safety Ramp — linear PWM scaling from 40% at 50°C to 100% at 200°C
// ============================================================================
const double SAFETY_RAMP_START_TEMP  = 50.0;    // ramp starts here
const double SAFETY_RAMP_END_TEMP    = 200.0;   // ramp ends here (full unlock)
const float  SAFETY_RAMP_MIN_LIMIT   = 0.40;    // 40% max below start temp
bool safetyRampActive = true;

// ============================================================================
// MOSFET Bang-Bang Control
// ============================================================================
// LEDC PWM didn't drive the MOSFET gate properly (0.8V vs expected 3.3V).
// Instead, we use time-proportioned bang-bang: over a 1-second window,
// the MOSFET is ON for (pidOutput/255)*CYCLE_MS ms and OFF for the rest.
// Thermal mass of the heater smooths this into steady power delivery.
const unsigned long MOSFET_CYCLE_MS = 1000;  // 1-second cycle
unsigned long mosfetCycleStart = 0;           // ms when current cycle began

// ============================================================================
// BLE State (ESP32 built-in NimBLE)
// ============================================================================
bool bleConnected = false;
bool bleActive = true;
unsigned long bleStartTime = 0;
const unsigned long BLE_PAIR_WINDOW = 120000;      // 2 minutes on boot
const unsigned long BLE_RECONNECT_WINDOW = 30000;  // 30 seconds on disconnect
unsigned long bleReconnectDeadline = 0;

BLEServer* pServer = nullptr;
BLECharacteristic* pNotifyChar = nullptr;
BLECharacteristic* pWriteChar = nullptr;
bool bleDisconnectTone = false;  // Flag for disconnect tone (played in main loop, not BLE callback)

unsigned long lastBleNotifyTime = 0;
const unsigned long BLE_NOTIFY_INTERVAL = 500;

// ============================================================================
// Audio — Melody State Machine
// ============================================================================
bool melodyPlaying = false;
int melodyNoteIndex = 0;
unsigned long nextActionTime = 0;
bool isNoteSilent = false;

int bootMelody[] = {
  NOTE_D4, -8, NOTE_G4, 16, NOTE_C5, -4, NOTE_B4, 8,
  NOTE_G4, -16, NOTE_E4, -16, NOTE_A4, -16, NOTE_D5, 2
};
int bootNotes = sizeof(bootMelody) / sizeof(bootMelody[0]) / 2;

int targetMelody[] = { NOTE_C4, -4, NOTE_G4, -4, NOTE_C5, 1 };
int targetNotes = sizeof(targetMelody) / sizeof(targetMelody[0]) / 2;

int entMelody[] = {
  NOTE_AS4, 8, NOTE_DS5, 8, NOTE_F5, 8, NOTE_F5, -4, NOTE_DS5, -2, REST, 1,
  NOTE_C5, 8, NOTE_AS4, 8, NOTE_AS4, 4, NOTE_AS4, 4, NOTE_G4, 8, NOTE_C5, 2, REST, 16,
  NOTE_AS4, 8, NOTE_DS5, 8, NOTE_F5, 8, NOTE_F5, -4, NOTE_DS5, -2, REST, -2,
  NOTE_DS5, 8, NOTE_F5, 4, NOTE_GS5, 4, NOTE_G5, 4, NOTE_F5, 4, NOTE_DS5, 8, NOTE_DS5, -2
};
int entNotes = sizeof(entMelody) / sizeof(entMelody[0]) / 2;

// ============================================================================
// Audio Helpers
// ============================================================================

void esp32Tone(int frequency, int duration = 0) {
  if (frequency == REST || frequency == 0) {
    ledcWriteTone(BUZZER_PWM_CHANNEL, 0);
  } else {
    ledcWriteTone(BUZZER_PWM_CHANNEL, frequency);
    if (duration > 0) {
      delay(duration);
      ledcWriteTone(BUZZER_PWM_CHANNEL, 0);
    }
  }
}

void esp32NoTone() {
  ledcWriteTone(BUZZER_PWM_CHANNEL, 0);
}

void playMelody(int melody[], int numNotes, int speed) {
  int wholenote = (60000 * 4) / speed;
  for (int thisNote = 0; thisNote < numNotes * 2; thisNote = thisNote + 2) {
    int divider = melody[thisNote + 1];
    int noteDuration = (divider > 0) ? (wholenote / divider) : (wholenote / abs(divider) * 1.5);
    
    esp32Tone(melody[thisNote]);
    unsigned long startDelay = millis();
    while (millis() - startDelay < (noteDuration * 0.9)) {
      yield();
    }
    esp32NoTone();
    startDelay = millis();
    while (millis() - startDelay < (noteDuration * 0.1)) {
      yield();
    }
  }
}

void updateMelody(int melody[], int numNotes, int speed) {
  if (!melodyPlaying) return;

  if (millis() >= nextActionTime) {
    if (!isNoteSilent) {
      if (melodyNoteIndex < numNotes * 2) {
        int divider = melody[melodyNoteIndex + 1];
        int wholenote = (60000 * 4) / speed;
        int noteDuration = (divider > 0) ? (wholenote / divider) : (wholenote / abs(divider) * 1.5);

        esp32Tone(melody[melodyNoteIndex]);
        nextActionTime = millis() + (noteDuration * 0.9);
        isNoteSilent = true;
      } else {
        melodyPlaying = false;
        melodyNoteIndex = 0;
        esp32NoTone();
      }
    } else {
      esp32NoTone();
      int divider = melody[melodyNoteIndex + 1];
      int wholenote = (60000 * 4) / speed;
      int noteDuration = (divider > 0) ? (wholenote / divider) : (wholenote / abs(divider) * 1.5);
      
      nextActionTime = millis() + (noteDuration * 0.1);
      isNoteSilent = false;
      melodyNoteIndex += 2;
    }
  }
}

// ============================================================================
// EEPROM Load/Save
// ============================================================================

void loadEEPROM() {
  EEData data;
  EEPROM.get(EEPROM_ADDR, data);
  
  if (isnan(data.setTemp) || data.setTemp < 0.0 || data.setTemp > MAX_TEMP) {
    data.setTemp = DEFAULT_SET_TEMP;
  }
  if (isnan(data.Kp) || data.Kp <= 0.0) data.Kp = DEFAULT_KP;
  if (isnan(data.Ki) || data.Ki < 0.0) data.Ki = DEFAULT_KI;
  if (isnan(data.Kd) || data.Kd < 0.0) data.Kd = DEFAULT_KD;
  
  setTemp = data.setTemp;
  pendingTemp = data.setTemp;
  Kp = data.Kp;
  Ki = data.Ki;
  Kd = data.Kd;
}

void saveEEPROM() {
  EEData data;
  data.setTemp = setTemp;
  data.Kp = Kp;
  data.Ki = Ki;
  data.Kd = Kd;
  EEPROM.put(EEPROM_ADDR, data);
  EEPROM.commit();
}

// ============================================================================
// BLE Callbacks (ESP32 built-in NimBLE)
// ============================================================================

class ServerCallbacks : public BLEServerCallbacks {
  void onConnect(BLEServer* pServer) override {
    bleConnected = true;
    bleReconnectDeadline = 0;  // Cancel any reconnect deadline on fresh connect
    bleStartTime = millis();    // Reset timeout baseline
    Serial.println(F("BLE: Client connected"));
  }

  void onDisconnect(BLEServer* pServer) override {
    bleConnected = false;
    // Schedule reconnect tone/advertising from main loop — do NOT block here.
    // delay() inside BLE callbacks blocks the NimBLE task and can cause GATT 133.
    bleDisconnectTone = true;
    if (bleActive && pServer != nullptr) {
      // Restart advertising immediately (lightweight — doesn't block)
      pServer->getAdvertising()->start();
      bleReconnectDeadline = millis() + BLE_RECONNECT_WINDOW;
      Serial.println(F("BLE: Reconnect window open for 30s"));
    }
  }
};

class WriteCallbacks : public BLECharacteristicCallbacks {
  void onWrite(BLECharacteristic* pCharacteristic) override {
    std::string value = pCharacteristic->getValue();
    if (value.length() == 0) return;

    JsonDocument doc;
    DeserializationError error = deserializeJson(doc, value);
    if (error) {
      Serial.print(F("JSON parse error: "));
      Serial.println(error.c_str());
      return;
    }

    const char* cmd = doc["cmd"];

    if (strcmp(cmd, "set_temp") == 0) {
      double newTemp = doc["val"].as<double>();
      newTemp = constrain(newTemp, 0.0, MAX_TEMP);
      setTemp = newTemp;
      if (!setMode) pendingTemp = newTemp;
      saveEEPROM();
      Serial.print(F("BLE set_temp: "));
      Serial.println(setTemp);
    }
    else if (strcmp(cmd, "arm") == 0) {
      int val = doc["val"].as<int>();
      if (val == 1 && !systemArmed) {
        systemArmed = true;
        sessionStartTime = millis();
        sessionElapsed = 0;
        targetReachedNotified = false;
        thermalRunawayCount = 0;
        redAlertActive = false;
        safetyRampActive = true;
        esp32Tone(1500, 500);
        Serial.println(F("BLE: ARMED"));
      } else if (val == 0 && systemArmed) {
        systemArmed = false;
        digitalWrite(PIN_MOSFET, LOW);
        pidOutput = 0;
        sessionElapsed = 0;
        esp32Tone(500, 500);
        Serial.println(F("BLE: DISARMED"));
      }
    }
    else if (strcmp(cmd, "e_stop") == 0) {
      systemArmed = false;
      redAlertActive = false;
      digitalWrite(PIN_MOSFET, LOW);
      pidOutput = 0;
      sessionElapsed = 0;
      safetyRampActive = true;
      esp32Tone(3000, 300);
      delay(100);
      esp32Tone(3000, 300);
      delay(100);
      esp32Tone(3000, 300);
      Serial.println(F("BLE: EMERGENCY STOP"));
    }
    else if (strcmp(cmd, "get_status") == 0) {
      lastBleNotifyTime = 0;  // Force immediate status send
    }
    else if (strcmp(cmd, "set_pid") == 0) {
      if (doc.containsKey("kp")) Kp = doc["kp"].as<double>();
      if (doc.containsKey("ki")) Ki = doc["ki"].as<double>();
      if (doc.containsKey("kd")) Kd = doc["kd"].as<double>();
      myPID.SetTunings(Kp, Ki, Kd);
      saveEEPROM();
      Serial.print(F("BLE set_pid: Kp=")); Serial.print(Kp);
      Serial.print(F(" Ki=")); Serial.print(Ki);
      Serial.print(F(" Kd=")); Serial.println(Kd);
    }
  }
};

// ============================================================================
// BLE Setup (ESP32 built-in NimBLE)
// ============================================================================

void setupBLE() {
  BLEDevice::init("WarpCore-eHMD");
  
  // NimBLE v3.x: bonding disabled by default (sm_bonding=0)
  // No security config needed — Just Works pairing, no passkey
  // The 2-minute BLE advertising window is the access control,
  // not encryption. After window, BLE sleeps until reboot.
  // IMPORTANT: Forget this device on your phone before pairing!
  
  pServer = BLEDevice::createServer();
  pServer->setCallbacks(new ServerCallbacks());
  
  BLEService* pService = pServer->createService(SERVICE_UUID);
  
  // Write characteristic — app sends JSON commands
  pWriteChar = pService->createCharacteristic(
    CHAR_WRITE_UUID,
    BLECharacteristic::PROPERTY_WRITE_NR | BLECharacteristic::PROPERTY_READ
  );
  pWriteChar->setCallbacks(new WriteCallbacks());
  
  // Notify characteristic — ESP32 pushes status JSON to app
  pNotifyChar = pService->createCharacteristic(
    CHAR_NOTIFY_UUID,
    BLECharacteristic::PROPERTY_NOTIFY | BLECharacteristic::PROPERTY_READ
  );
  pNotifyChar->addDescriptor(new BLE2902());
  
  pService->start();
  
  // Start advertising — 2-minute window
  BLEAdvertising* pAdvertising = pServer->getAdvertising();
  pAdvertising->start();
  bleStartTime = millis();
  bleActive = true;
  Serial.println(F("BLE: Advertising as 'WarpCore-eHMD' — 2 min window"));
}

// ============================================================================
// BLE Status Send
// ============================================================================

void sendBleStatus() {
  if (!bleConnected || !pNotifyChar) return;
  
  JsonDocument doc;
  
  if (redAlertActive) {
    doc["status"] = "red_alert";
  } else if (isnan(actualTemp)) {
    doc["status"] = "error";
    doc["msg"] = "sensor_fault";
  } else {
    doc["status"] = "ok";
  }
  
  doc["temp_set"] = (int)setTemp;
  doc["temp_actual"] = isnan(actualTemp) ? -1 : (int)(actualTemp + 0.5);
  doc["armed"] = systemArmed ? 1 : 0;
  doc["pwm"] = (int)((pidOutput / 255.0) * 100.0);
  doc["pid_raw"] = (int)pidOutput;
  doc["session"] = (int)sessionElapsed;
  
  // Debug fields — PID internals
  JsonObject dbg = doc.createNestedObject("dbg");
  dbg["kp"] = roundf(Kp * 100.0) / 100.0;
  dbg["ki"] = roundf(Ki * 100.0) / 100.0;
  dbg["kd"] = roundf(Kd * 100.0) / 100.0;
  dbg["err"] = roundf((setTemp - actualTemp) * 10.0) / 10.0;
  dbg["pwm_raw"] = (int)pidOutput;
  dbg["pin_state"] = digitalRead(PIN_MOSFET);  // bang-bang state: 1=ON, 0=OFF
  
  char buffer[384];
  serializeJson(doc, buffer, sizeof(buffer));
  pNotifyChar->setValue(buffer);
  pNotifyChar->notify();
}

// ============================================================================
// Button Handling
// ============================================================================
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
void loop() {
  handleButton();
  handleJoystickNavigation();
  updateMelody(entMelody, entNotes, 120);

  // Read sensors every 250ms
  if (millis() - lastTempTime > 250) {
    actualTemp = thermocouple.readCelsius();
    lastTempTime = millis();

    if (systemArmed && !targetReachedNotified && !redAlertActive && actualTemp >= setTemp) {
      melodyPlaying = true;
      targetReachedNotified = true;
    }

    checkThermalRunaway();
  }

  if (systemArmed) {
    sessionElapsed = (millis() - sessionStartTime) / 1000;
  }

  // PID Control & Safety — time-proportioned bang-bang for MOSFET
  if (isnan(actualTemp)) {
    digitalWrite(PIN_MOSFET, LOW);
    pidOutput = 0;
    if (millis() - lastAlarmTime > 1000) {
      esp32Tone(3000, 200);
      lastAlarmTime = millis();
    }
  } else if (!systemArmed) {
    digitalWrite(PIN_MOSFET, LOW);
    pidOutput = 0;
  } else {
    if (myPID.Compute()) {
      // Safety Ramp — linear scale: 40% at 50°C → 100% at 200°C
      if (safetyRampActive) {
        if (actualTemp >= SAFETY_RAMP_END_TEMP) {
          safetyRampActive = false;
          Serial.println(F("SAFETY RAMP: 200°C reached — full PID unlocked"));
        } else {
          // Linear interpolation from SAFETY_RAMP_MIN_LIMIT → 1.0 over temp range
          float t = constrain(actualTemp, SAFETY_RAMP_START_TEMP, SAFETY_RAMP_END_TEMP);
          float rampLimit = SAFETY_RAMP_MIN_LIMIT + (1.0 - SAFETY_RAMP_MIN_LIMIT) *
                            ((t - SAFETY_RAMP_START_TEMP) / (SAFETY_RAMP_END_TEMP - SAFETY_RAMP_START_TEMP));
          float capped255 = rampLimit * 255.0;
          if (pidOutput > capped255) pidOutput = capped255;
        }
      }

      // Bang-bang: over MOSFET_CYCLE_MS, hold HIGH for pidOutput/255 fraction
      unsigned long onTime = (unsigned long)(pidOutput / 255.0 * MOSFET_CYCLE_MS);
      unsigned long elapsed = millis() - mosfetCycleStart;
      if (elapsed >= MOSFET_CYCLE_MS) {
        mosfetCycleStart = millis();
        elapsed = 0;
      }
      if (onTime > 0 && elapsed < onTime) {
        digitalWrite(PIN_MOSFET, HIGH);
      } else {
        digitalWrite(PIN_MOSFET, LOW);
      }
    }
  }

  // Debug: print PID state every 2 seconds
  static unsigned long lastPidDebug = 0;
  if (millis() - lastPidDebug > 2000) {
    Serial.print(F("PID: out=")); Serial.print((int)pidOutput);
    Serial.print(F(" actual=")); Serial.print(actualTemp, 1);
    Serial.print(F(" set=")); Serial.print(setTemp, 1);
    Serial.print(F(" armed=")); Serial.print(systemArmed);
    Serial.print(F(" Kp=")); Serial.print(Kp, 2);
    Serial.print(F(" Ki=")); Serial.print(Ki, 2);
    Serial.print(F(" Kd=")); Serial.println(Kd, 2);
    lastPidDebug = millis();
  }

  if (redAlertActive) {
    if (millis() - lastAlarmTime > 500) {
      esp32Tone(3000, 200);
      lastAlarmTime = millis();
    }
  }

  if (millis() - lastDisplayUpdate > 500) {
    updateDisplay();
    lastDisplayUpdate = millis();
  }

  // Play disconnect tone in main loop (never in BLE callback — it blocks NimBLE)
  if (bleDisconnectTone) {
    bleDisconnectTone = false;
    esp32Tone(800, 150);
    delay(100);
    esp32Tone(400, 200);
  }

  // Send BLE status every 500ms when connected
  if (bleConnected && (millis() - lastBleNotifyTime > BLE_NOTIFY_INTERVAL)) {
    sendBleStatus();
    lastBleNotifyTime = millis();
  }

  // BLE timeout — stop advertising if no connection established
  if (bleActive && !bleConnected) {
    if (bleStartTime > 0 && bleReconnectDeadline == 0) {
      if (millis() - bleStartTime > BLE_PAIR_WINDOW) {
        pServer->getAdvertising()->stop();
        bleActive = false;
        Serial.println(F("BLE: Pairing window expired — BLE sleeping"));
      }
    }
    if (bleReconnectDeadline > 0 && millis() > bleReconnectDeadline) {
      pServer->getAdvertising()->stop();
      bleActive = false;
      bleReconnectDeadline = 0;
      Serial.println(F("BLE: Reconnect window expired — BLE sleeping"));
    }
  }
}

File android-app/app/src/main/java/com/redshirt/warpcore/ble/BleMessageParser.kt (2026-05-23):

package com.redshirt.warpcore.ble

import com.redshirt.warpcore.data.DeviceStatus
import com.google.gson.Gson
import com.google.gson.JsonSyntaxException

/**
 * Parser for BLE JSON messages from the eHMD ESP32.
 * See docs/BLE_PROTOCOL.md for the full specification.
 */
object BleMessageParser {
    private val gson = Gson()

    /**
     * Parse a status notification from ESP32.
     * Expected JSON: {"status":"ok","temp_set":200,"temp_actual":198,"armed":1,"pwm":73,"battery":85,"session":1847}
     */
    fun parseStatus(jsonString: String): DeviceStatus? {
        return try {
            val json = gson.fromJson(jsonString, Map::class.java)
            val dbg = json["dbg"] as? Map<*, *>
            DeviceStatus(
                status = json["status"] as? String ?: "ok",
                msg = json["msg"] as? String,
                tempSet = (json["temp_set"] as? Double)?.toInt() ?: 0,
                tempActual = (json["temp_actual"] as? Double)?.toInt() ?: -1,
                armed = (json["armed"] as? Double)?.toInt() == 1,
                pwm = (json["pwm"] as? Double)?.toInt() ?: 0,
                pidRaw = (json["pid_raw"] as? Double)?.toInt() ?: 0,
                battery = (json["battery"] as? Double)?.toInt() ?: 0,
                session = (json["session"] as? Double)?.toInt() ?: 0,
                debugKp = (dbg?.get("kp") as? Double) ?: 0.0,
                debugKi = (dbg?.get("ki") as? Double) ?: 0.0,
                debugKd = (dbg?.get("kd") as? Double) ?: 0.0,
                debugError = (dbg?.get("err") as? Double) ?: 0.0,
                debugPwmRaw = (dbg?.get("pwm_raw") as? Double)?.toInt() ?: 0,
                debugVoltage = (dbg?.get("voltage") as? Double) ?: 0.0
            )
        } catch (e: JsonSyntaxException) {
            null
        } catch (e: Exception) {
            null
        }
    }

    /**
     * Build a set_temp command JSON.
     * val is in Celsius, 0-400.
     */
    fun buildSetTemp(tempCelsius: Int): String {
        return """{"cmd":"set_temp","val":$tempCelsius}"""
    }

    /**
     * Build an arm/disarm command JSON.
     */
    fun buildArm(armed: Boolean): String {
        val armVal = if (armed) 1 else 0
        return """{"cmd":"arm","val":$armVal}"""
    }

    /**
     * Build an emergency stop command JSON.
     */
    fun buildEStop(): String {
        return """{"cmd":"e_stop"}"""
    }

    /**
     * Build a get_status request command JSON.
     */
    fun buildGetStatus(): String {
        return """{"cmd":"get_status"}"""
    }

    /**
     * Build a set_pid command JSON.
     */
    fun buildSetPid(kp: Double, ki: Double, kd: Double): String {
        return """{"cmd":"set_pid","kp":$kp,"ki":$ki,"kd":$kd}"""
    }

    // BLE UUIDs
    const val SERVICE_UUID = "4fafc201-1fb5-459e-8fcc-c5c9c331914b"
    const val WRITE_CHAR_UUID = "beb5483e-36e1-4688-b7f5-ea07361b26a8"
    const val NOTIFY_CHAR_UUID = "beb5483e-36e1-4688-b7f5-ea07361b26a9"
    const val DEVICE_NAME = "Warp Core eHMD"
}

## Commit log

2026-05-23 Initial commit: Warp Core eHMD v1.0
    Android app (Kotlin + Jetpack Compose) with BLE control,
    PID temp slider with ±1–10 step size, profiles, session logging.
    Arduino Nano ESP32 firmware with PID-controlled 20kHz PWM,
    MAX6675 thermocouple, SSD1306 OLED, buzzer, LiPo monitoring.
    3D-printable enclosure STLs, assembly instructions, BLE protocol docs.
    [Warp Core - Box Bottom.stl, Warp Core - Box Latch.stl, Warp Core - Box Lid.stl]
2026-05-23 Add MIT license and full project README
    - MIT LICENSE file
    - Comprehensive README with BOM, pin assignments, assembly link,
    quick start, BLE protocol summary, project structure, safety notice
2026-05-23 feat: add debug screen + PID serial output
    Arduino:
    - Add 2-second PID debug Serial output (out, actual, set, armed, Kp/Ki/Kd)
    - Add pid_raw and dbg object to BLE JSON (Kp, Ki, Kd, error, voltage)
    Android:
    - New Debug screen tab showing PID raw output, temperature delta,
    PID tuning values, system voltage, and raw JSON
    - DeviceStatus parses pid_raw and dbg sub-object
    - BleMessageParser extracts debug fields from BLE notifications
    - Fixed status bar underlap (enableEdgeToEdge + statusBarsPadding)
    [BleMessageParser.kt, DebugScreen.kt, WarpCore_eHMD.ino]
2026-05-24 fix: ESP32 LEDC v3.x pin-based API — MOSFET was writing to GPIO 1 instead of D9
    ESP32 Arduino Core v3.x changed ledcWrite/ledcWriteTone to take pin numbers
    instead of channel numbers. Old channel-based calls silently wrote to the
    wrong GPIO. This fix:
    - Replaced ledcSetup+ledcAttachPin with ledcAttach(pin, freq, res)
    - Changed all ledcWrite(MOSFET_PWM_CHANNEL, ...) to ledcWrite(PIN_MOSFET, ...)
    - Changed all ledcWriteTone(BUZZER_PWM_CHANNEL, ...) to ledcWriteTone(PIN_BUZZER, ...)
    - Removed BUZZER_PWM_CHANNEL and MOSFET_PWM_CHANNEL constants
    - Added MOSFET_PWM_RES constant for clarity
    [WarpCore_eHMD.ino]
2026-05-24 Revert "fix: ESP32 LEDC v3.x pin-based API — MOSFET was writing to GPIO 1 instead of D9"
    This reverts commit 90f061db9d7c7c0c0c392b1f7b10c1d10297b326.
    [WarpCore_eHMD.ino]
2026-05-24 fix: move MOSFET from D9 to D4 — GPIO 9 conflict driving pin low
    D9/GPIO9 was reading 0.7V under load despite passing bare pin tests.
    Moved MOSFET output to D4. D4 tested clean at 3.3V in isolation.
    Re-wire hardware: move MOSFET gate from D9 to D4.
    [WarpCore_eHMD.ino]
2026-05-24 diagnostic: force digitalWrite on MOSFET pin + expose pin_state via BLE
    Testing if LEDC is the problem. digitalWrite bypasses the PWM peripheral
    entirely. If pin reads 3.3V with this, LEDC is misconfigured. Added
    pin_state to BLE dbg object so we can read digitalRead from the app.
    [WarpCore_eHMD.ino]
2026-05-24 fix: replace LEDC PWM with time-proportioned bang-bang for MOSFET
    LEDC produced only ~0.8V on the MOSFET gate (confirmed via digitalWrite
    test at 3.3V). Root cause unclear — possibly LEDC/timer conflict or GPIO
    mux issue on this board. Bang-bang control sidesteps the problem entirely:
    - MOSFET driven by digitalWrite HIGH/LOW (no LEDC peripheral)
    - PID output 0-255 maps to ON fraction within a 1-second cycle
    - Heater thermal mass smooths the 1Hz cycling into steady power
    - Zero audible noise (no PWM carrier at all)
    Removed MOSFET_PWM_FREQ constant (unused). MOSFET_PWM_CHANNEL kept as
    guard constant (-1). All ledcWrite(MOSFET_PWM_CHANNEL,0) replaced with
    digitalWrite(PIN_MOSFET, LOW). Pin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
    [WarpCore_eHMD.ino]
2026-06-13 reassign OLED I2C from A4/A5 to D2(SDA)/D3(SCL)
2026-06-13 remove voltage hardware, add safety ramp (40% PWM cap until 200°C)
2026-06-24 docs: update README for battery-removal, safety ramp, I2C/D4 pin changes + WIP banner
2026-06-24 docs: add current challenges to WIP banner (PD overcurrent + MCH selection)
